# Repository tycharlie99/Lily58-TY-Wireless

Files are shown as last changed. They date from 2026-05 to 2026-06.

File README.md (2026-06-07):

# TsunyYu - Lily58

An ergonomic, split mechanical keyboard with a 58-key columnar-staggered layout, derived from the original [Lily58](https://github.com/kata0510/Lily58). This specific variant is optimized for wireless dual-mode connectivity and ultra-low-power Nice!View displays, perfect for developers and creators seeking a clean, cable-free workspace.

## Features

- **Ergonomic Columnar Layout**: 4x12 matrix with 5 thumb keys per side (58 keys total) reduces finger travel and hand strain.
- **Wireless-Ready**: Integrated battery support for seamless Bluetooth operation when paired with BLE controllers (e.g., nice!nano).
- **Nice!View Optimization**: Native compatibility with the low-power Sharp Memory Display (Nice!View), offering a high refresh rate with a fraction of the power consumption of traditional OLEDs.
- **Reversible PCB Design**: Uses a mirrored, flippable design for the left and right sides to simplify manufacturing and sourcing.
---

## Bill of Materials (BOM)

Below is the complete list of components required to build one full TsunyYu - Lily58 keyboard (including both left and right halves):

| Item | Quantity | Model/Specification / Notes |
| --- | --- | --- |
| **Lily58 PCB** | 2 | Left and right halves (reversible design) |
| **PCB Plate** | 2 | Left and right halves (compatible with 58-key layout) |
| **Microcontroller** | 2 | Pro Micro or compatible BLE wireless controllers (e.g., nice!nano) |
| **Display** | 2 | Nice!View (Ultra-low-power display; backward compatible with 0.91" OLED) |
| **Key Socket** | 58 | Kailh Hotswap Sockets |
| **Switches** | 58 | MX switches |
| **Keycaps** | 58 | 1U keycaps recommended, 1.5U optional for thumb keys |
| **Diodes** | 58 | 1N4148W (SOD-123) |
| **Resistors** | 4 | 4k7 ohm (0603) Used for I2C/Display signal stability |
| **TRRS Jack** | 2 | PJ-320A or equivalent (for wired connection between halves) |
| **Batteries** | 2 | 3.7V Li-Po batteries (Required for wireless; 110mAh to 300mAh recommended) |
| **Battery Holders** | 2 | JST GH 1.25mm 2p |
| **Reset Buttons** | 2 | KXT 321 |

---

## Hardware & Soldering Guide

Please review these critical steps before heating up your soldering iron:

1. **Orientation Check**: Because the PCB is reversible, make sure you clearly identify the "Left" and "Right" sides before soldering any components. Do not accidentally mirror the components on the same side.
2. **Diode Polarity**: Diodes are directional. Ensure the line on the diode (cathode) aligns with the thick line/bar indicated on the PCB silkscreen markings.
3. **Wireless Safety Precautions**:
   - Always unplug the battery from the **JST GH connector** before soldering/desoldering any components nearby to prevent accidental short circuits.
   - It is highly recommended to apply **insulating tape** (like Kapton tape) over the PCB traces beneath the microcontroller to prevent shorts between the controller pins and the PCB components/battery.
   - Pay close attention to the pinout when installing the Nice!View. It requires 5 pins (including a CS pin), differing slightly from standard 4-pin OLED setups.

---

## Firmware Support

This build is fully compatible with open-source keyboard firmwares:

- **ZMK Firmware (Highly Recommended)**: The ideal choice when paired with nice!nano controllers. It natively handles Bluetooth multi-device pairing and unlocks the full low-power efficiency of the Nice!View screen.
- **QMK Firmware**: Best suited for standard wired setups using traditional Pro Micro controllers.

---

## References & Credits

This project is built upon and inspired by the incredible open-source work of the mechanical keyboard community:

- [kata0510/Lily58](https://github.com/kata0510/Lily58) - The original Lily58 design.
- [ZMK Firmware](https://zmk.dev/) & [nice!nano](https://nicekeyboards.com/) - Providing the robust ecosystem for wireless split keyboards.

---

## License

This hardware project is open-source and distributed under the same licensing terms as the original repository:
- **Distributed under the [MIT License](LICENSE)** *(Or specify CERN OHL if applicable to your custom PCB modifications).*

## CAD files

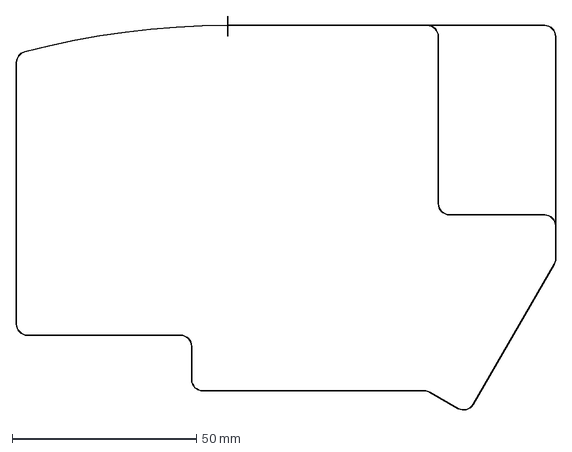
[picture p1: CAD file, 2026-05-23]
PCB/lily58 plate.dxf
146.4 x 107.3 mm

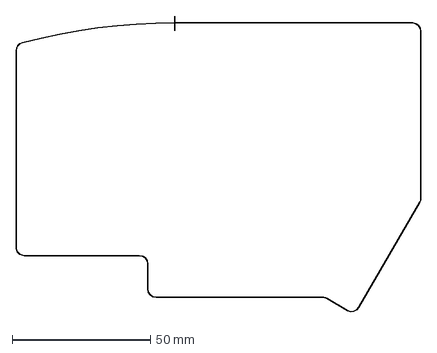
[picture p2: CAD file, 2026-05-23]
PCB/lily58 edge cut.dxf
146.4 x 107.3 mm

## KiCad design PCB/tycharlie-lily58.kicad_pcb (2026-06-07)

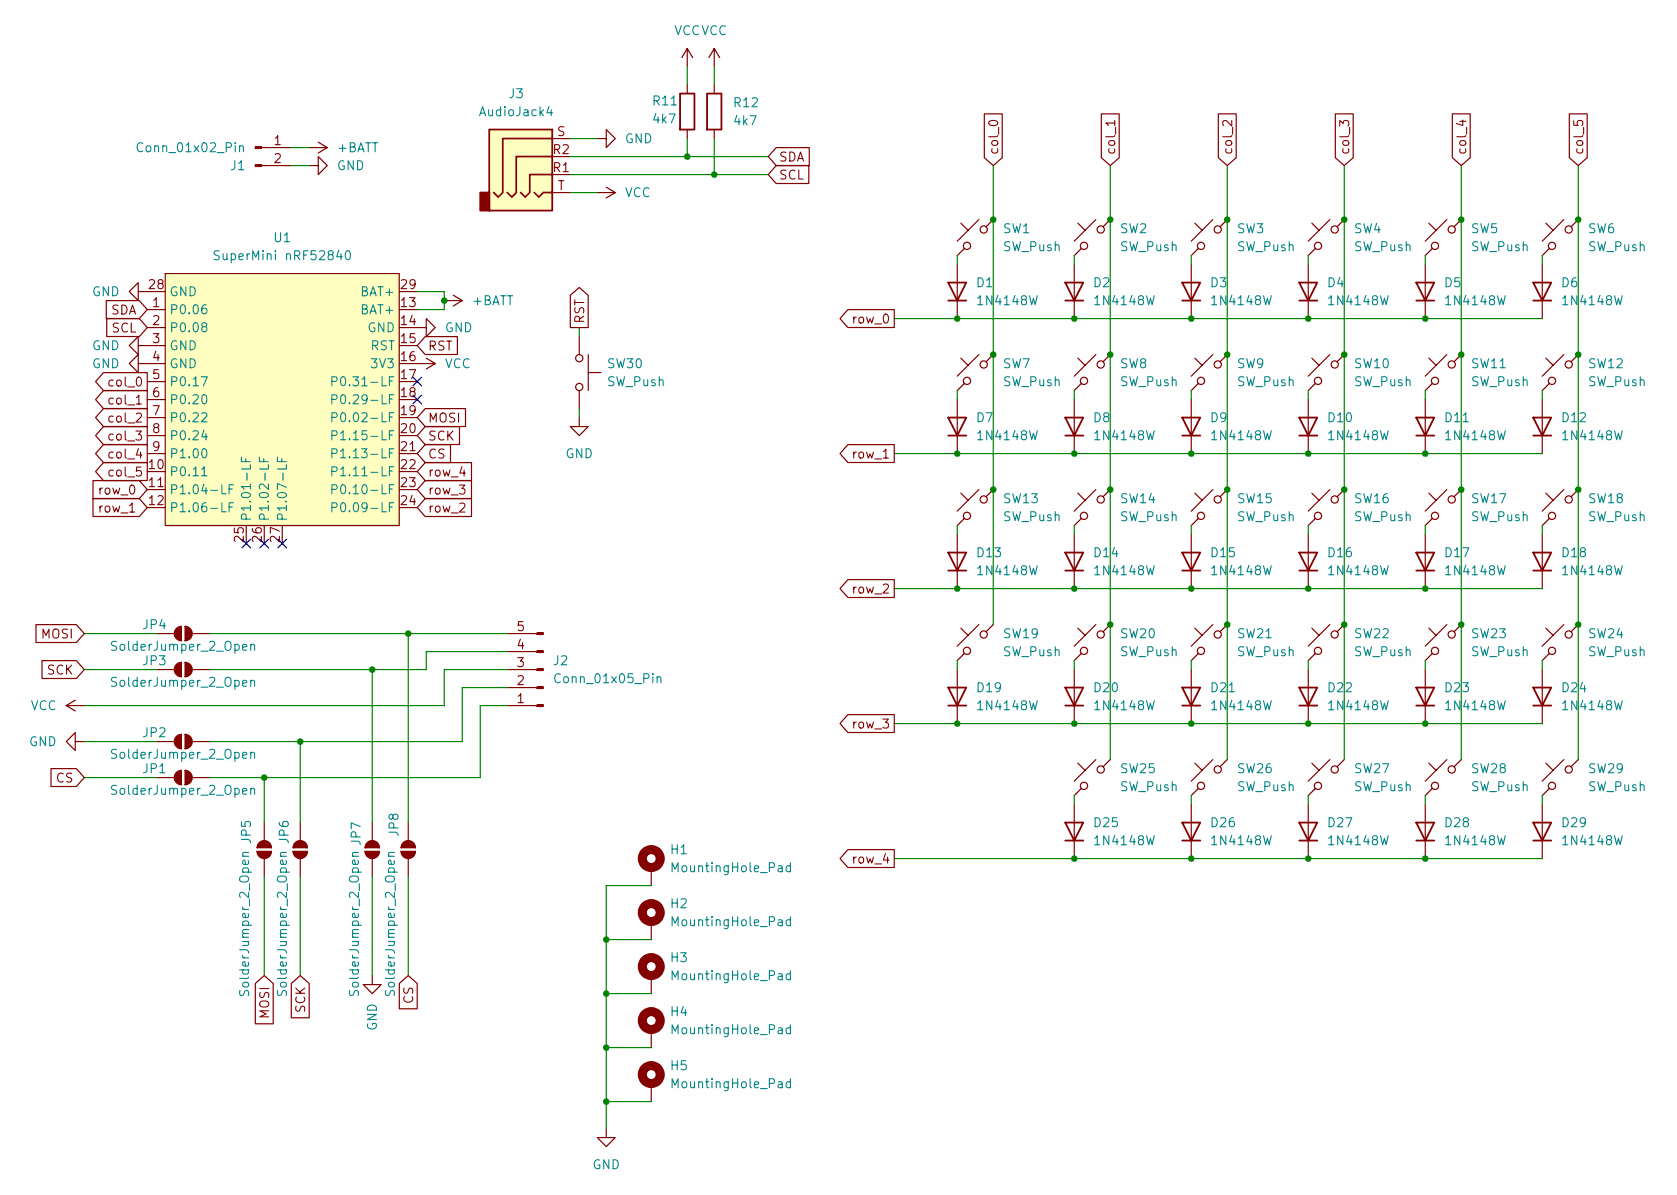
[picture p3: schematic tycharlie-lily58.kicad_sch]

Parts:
D1, D2, D3, D4, D5, D6, D7, D8, D9, D10, D11, D12, D13, D14, D15, D16, D17, D18, D19, D20, D21, D22, D23, D24, D25, D26, D27, D28, D29: 1N4148W; D_SOD-123
H1, H2, H4: MountingHole_Pad; MountingHole_3mm_Oval_Hole_ISO14580_Pad_TopBottom
H3: MountingHole_Pad; MountingHole_2.2mm_M2_ISO14580_Pad_TopBottom
H5: MountingHole_Pad; MountingHole_3mm_M2_ISO14580_Pad_TopBottom
J1: Conn_01x02_Pin; Molex_PicoBlade_53261-0271_1x02-1MP_P1.25mm_Horizontal
J2: Conn_01x05_Pin; PinHeader_1x05_P2.54mm_Vertical
J3: AudioJack4; CON_MJ-4PP-9_Reversible
JP1, JP2, JP3, JP4, JP5, JP6, JP7, JP8: SolderJumper_2_Open; SolderJumper-2_P1.3mm_Open_RoundedPad1.0x1.5mm
R11, R12: 4k7; R_0603_1608Metric_Pad0.98x0.95mm_HandSolder
SW1, SW2, SW3, SW4, SW5, SW6, SW7, SW8, SW9, SW10, SW11, SW12, SW13, SW14, SW15, SW16, SW17, SW18, SW19, SW20, SW21, SW22, SW23, SW24, SW25, SW26, SW27, SW29: SW_Push; SW_Hotswap_Reversible_Kailh_MX_Plated_1.00u
SW28: SW_Push; SW_Hotswap_Reversible_Kailh_MX_Plated_1.50u
SW30: SW_Push; SW_SPST_CK_KXT3
U1: SuperMini nRF52840; SuperMini_nRF52840_without_25-27

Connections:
+BATT: J1.1, U1.13 (BAT+), U1.29 (BAT+)
CS: JP1.1 (A), JP8.1 (A), U1.21 (P1.13-LF)
GND: H1.1 (1_1), H2.1 (1_1), H3.1 (1_1), H4.1 (1_1), H5.1 (1_1), J1.2, J3.S, JP2.1 (A), JP7.1 (A), SW30.2, U1.3 (GND), U1.4 (GND), U1.14 (GND), U1.28 (GND)
MOSI: JP4.1 (A), JP5.1 (A), U1.19 (P0.02-LF)
unnamed: D1.2 (A), SW1.1
unnamed: D2.2 (A), SW2.1
unnamed: D3.2 (A), SW3.1
unnamed: D4.2 (A), SW4.1
unnamed: D5.2 (A), SW5.1
unnamed: D6.2 (A), SW6.1
unnamed: D7.2 (A), SW7.1
unnamed: D8.2 (A), SW8.1
unnamed: D9.2 (A), SW9.1
unnamed: D10.2 (A), SW10.1
unnamed: D11.2 (A), SW11.1
unnamed: D12.2 (A), SW12.1
unnamed: D13.2 (A), SW13.1
unnamed: D14.2 (A), SW14.1
unnamed: D15.2 (A), SW15.1
unnamed: D16.2 (A), SW16.1
unnamed: D17.2 (A), SW17.1
unnamed: D18.2 (A), SW18.1
unnamed: D19.2 (A), SW19.1
unnamed: D20.2 (A), SW20.1
unnamed: D21.2 (A), SW21.1
unnamed: D22.2 (A), SW22.1
unnamed: D23.2 (A), SW23.1
unnamed: D24.2 (A), SW24.1
unnamed: D25.2 (A), SW25.1
unnamed: D26.2 (A), SW26.1
unnamed: D27.2 (A), SW27.1
unnamed: D28.2 (A), SW28.1
unnamed: D29.2 (A), SW29.1
unnamed: J2.1, JP1.2 (B), JP5.2 (B)
unnamed: J2.2, JP2.2 (B), JP6.2 (B)
unnamed: J2.4, JP3.2 (B), JP7.2 (B)
unnamed: J2.5, JP4.2 (B), JP8.2 (B)
RST: SW30.1, U1.15 (RST)
SCK: JP3.1 (A), JP6.1 (A), U1.20 (P1.15-LF)
SCL: J3.R1, R12.2, U1.2 (P0.08)
SDA: J3.R2, R11.2, U1.1 (P0.06)
VCC: J2.3, J3.T, R11.1, R12.1, U1.16 (3V3)
col_0: SW1.2, SW7.2, SW13.2, SW19.2, U1.5 (P0.17)
col_1: SW2.2, SW8.2, SW14.2, SW20.2, SW25.2, U1.6 (P0.20)
col_2: SW3.2, SW9.2, SW15.2, SW21.2, SW26.2, U1.7 (P0.22)
col_3: SW4.2, SW10.2, SW16.2, SW22.2, SW27.2, U1.8 (P0.24)
col_4: SW5.2, SW11.2, SW17.2, SW23.2, SW28.2, U1.9 (P1.00)
col_5: SW6.2, SW12.2, SW18.2, SW24.2, SW29.2, U1.10 (P0.11)
row_0: D1.1 (K), D2.1 (K), D3.1 (K), D4.1 (K), D5.1 (K), D6.1 (K), U1.11 (P1.04-LF)
row_1: D7.1 (K), D8.1 (K), D9.1 (K), D10.1 (K), D11.1 (K), D12.1 (K), U1.12 (P1.06-LF)
row_2: D13.1 (K), D14.1 (K), D15.1 (K), D16.1 (K), D17.1 (K), D18.1 (K), U1.24 (P0.09-LF)
row_3: D19.1 (K), D20.1 (K), D21.1 (K), D22.1 (K), D23.1 (K), D24.1 (K), U1.23 (P0.10-LF)
row_4: D25.1 (K), D26.1 (K), D27.1 (K), D28.1 (K), D29.1 (K), U1.22 (P1.11-LF)

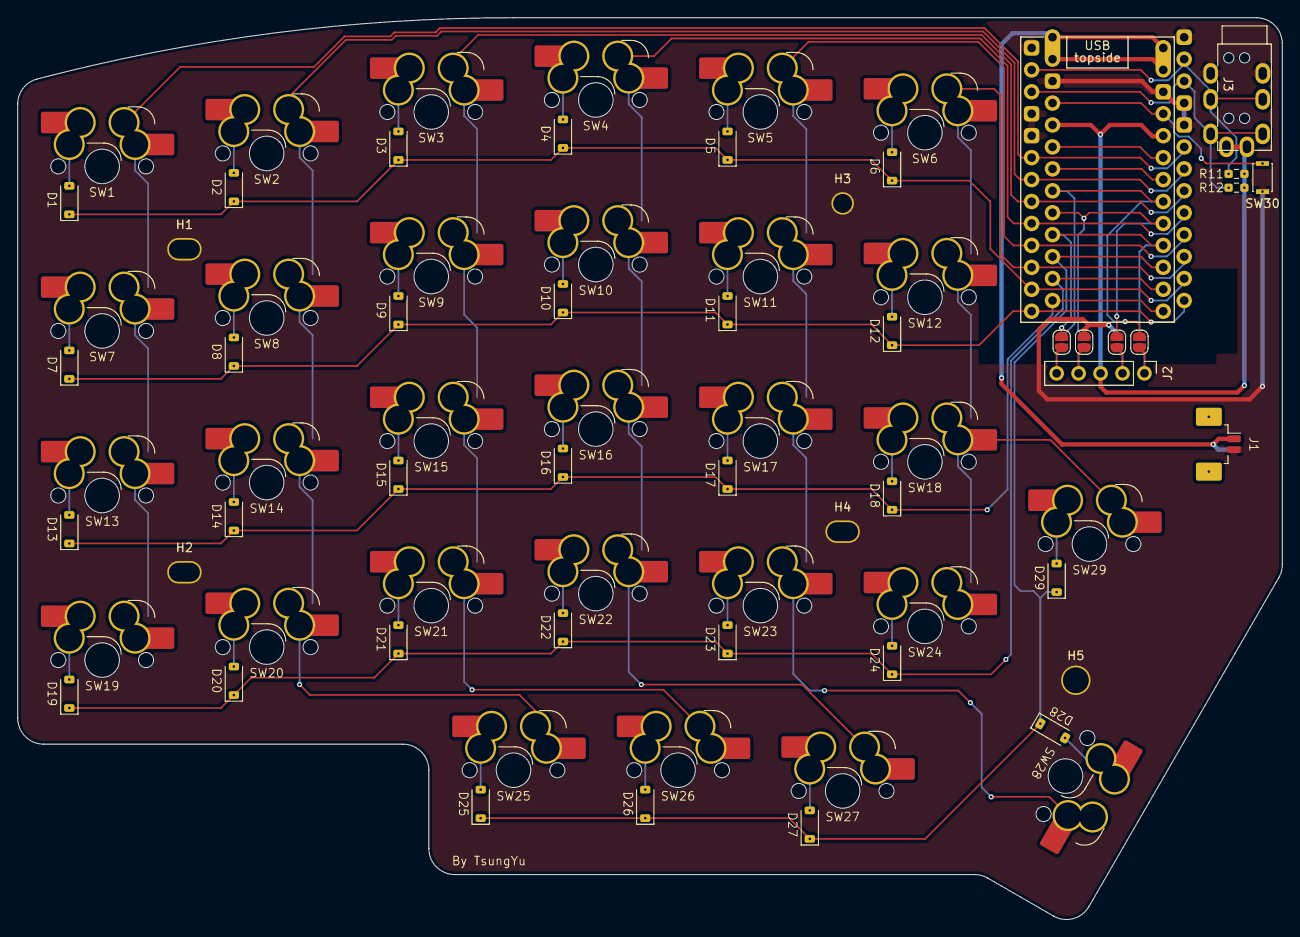
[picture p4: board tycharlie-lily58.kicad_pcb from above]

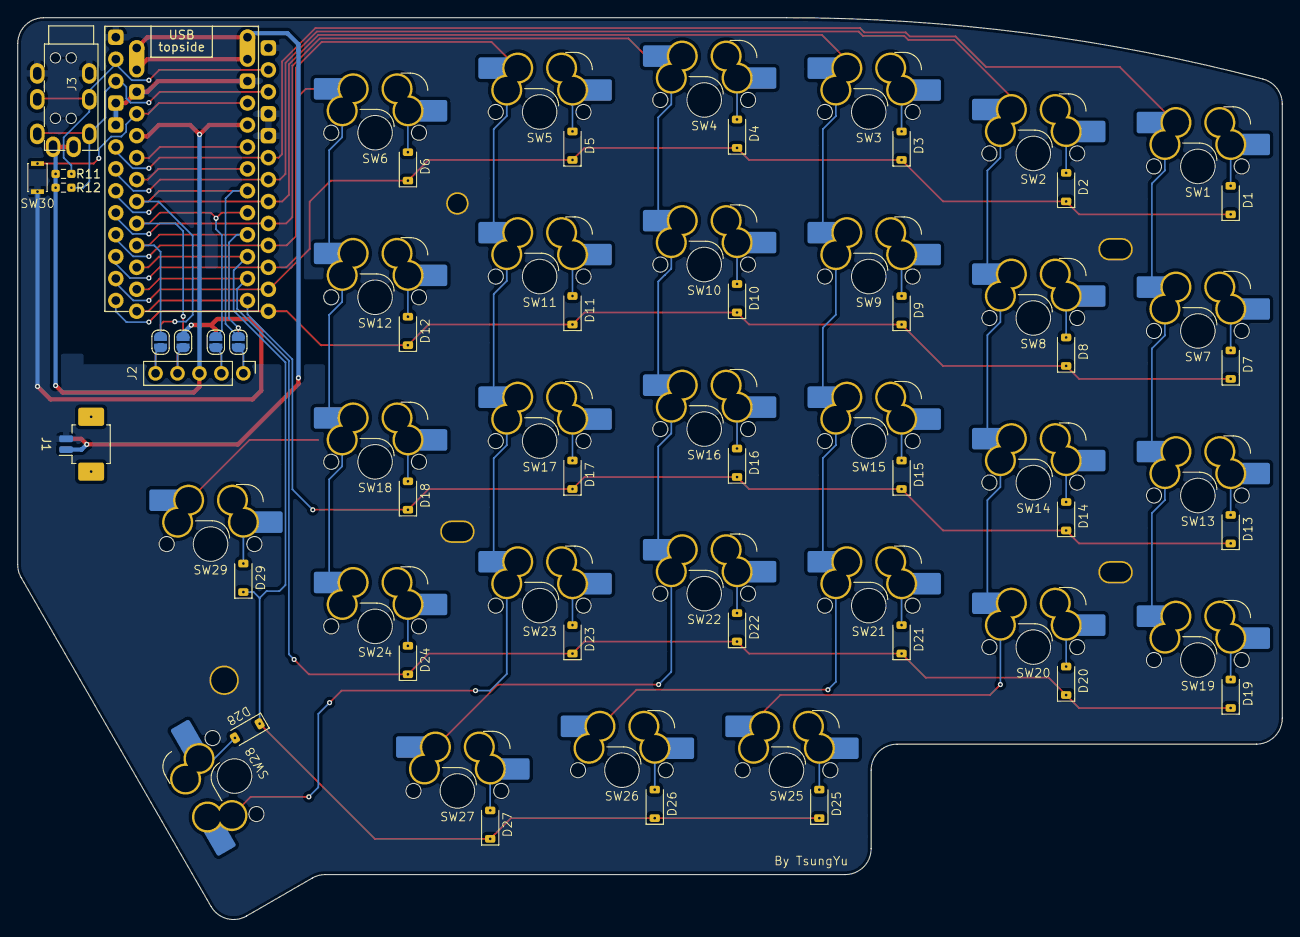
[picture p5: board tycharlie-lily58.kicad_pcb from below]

Board: 2 copper layers, 146.4 x 104.4 mm, 78 parts (36 on the bottom side), 53 nets.

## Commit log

2026-05-23 FEAT: add the pcb data finish the schematic design and the pcb layout
    [tycharlie-lily58.kicad_pcb, tycharlie-lily58.kicad_sch]
2026-05-23 FEAT: add the dxf file for edge cut - use the dxf file to maintain the edge cut - add two different mounting hole - use larger mounting hole for robustness
    [lily58 edge cut.dxf, tycharlie-lily58.kicad_pcb, tycharlie-lily58.kicad_sch]
2026-05-23 FIX: fix the group issue the group item in the pcb will not correctly when using the different version, regroup them
    [lily58 edge cut.dxf, tycharlie-lily58.kicad_pcb]
2026-05-23 FEAT: add the keyboard plate
    [lily58 plate.dxf, tycharlie-lily58.kicad_pcb, tycharlie-lily58_Plate.kicad_pcb]
2026-05-24 FIX: update the plate mounting hole size
    [tycharlie-lily58.kicad_pcb, tycharlie-lily58_Plate.kicad_pcb]
2026-06-07 CHORE: add the name on pcb
    [tycharlie-lily58.kicad_pcb, tycharlie-lily58_Plate.kicad_pcb]
2026-06-07 FIX: update the battery footprint
    - Add new Molex PicoBlade 53261 foorprint
    - Changed the battery pin1 to BATT+
    [tycharlie-lily58.kicad_pcb, tycharlie-lily58.kicad_sch]
2026-06-13 FEAT: update plate mounting hole size
    - change the mounting hole to 5mm
    - renamed the mounting hole footprint name
    [tycharlie-lily58_Plate.kicad_pcb]
